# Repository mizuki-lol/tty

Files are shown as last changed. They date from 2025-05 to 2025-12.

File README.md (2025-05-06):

# Převodník ASCII na ITA-2

Tento projekt slouží k připojení zařízení pomocí sériového kabelu k dálnopisu.

## Konstrukce

K sestavení převodníku je potřeba:
  * Raspberry Pi Pico 1
  * Převodník RS-232 - TTL
  * 2x optočlen
  * 4x 300 Ohm rezistor
  * 1x LED dioda
  * Nepájivé pole
  * Dráty pro propojení součástek na nepájivém poli

Zapojte podle obrázku nebo dle schémata ve složce `schematics/`.
Dbejte na orientaci diody a optočlenů, správné zapojení je na obrázku.
Nezapomeňte připojit napěťovou smyčku dálnopisu k spodním napájecím kontaktům (označené + a -).
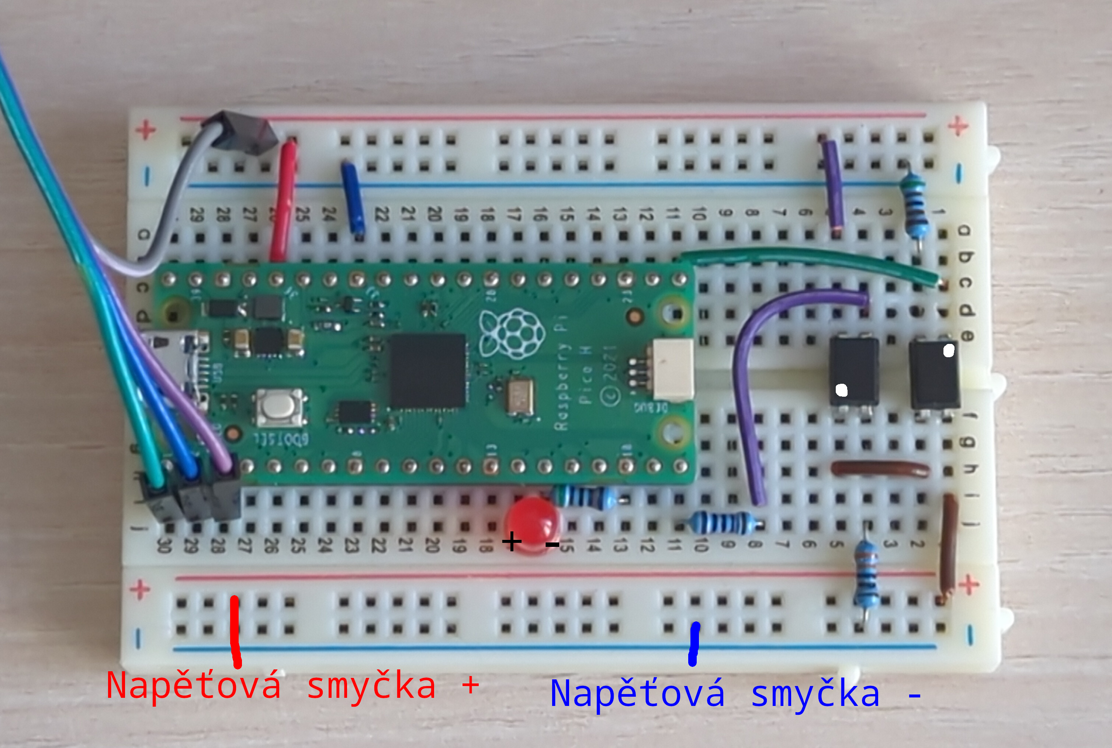
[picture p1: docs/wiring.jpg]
Zapojení na nepájivém poli

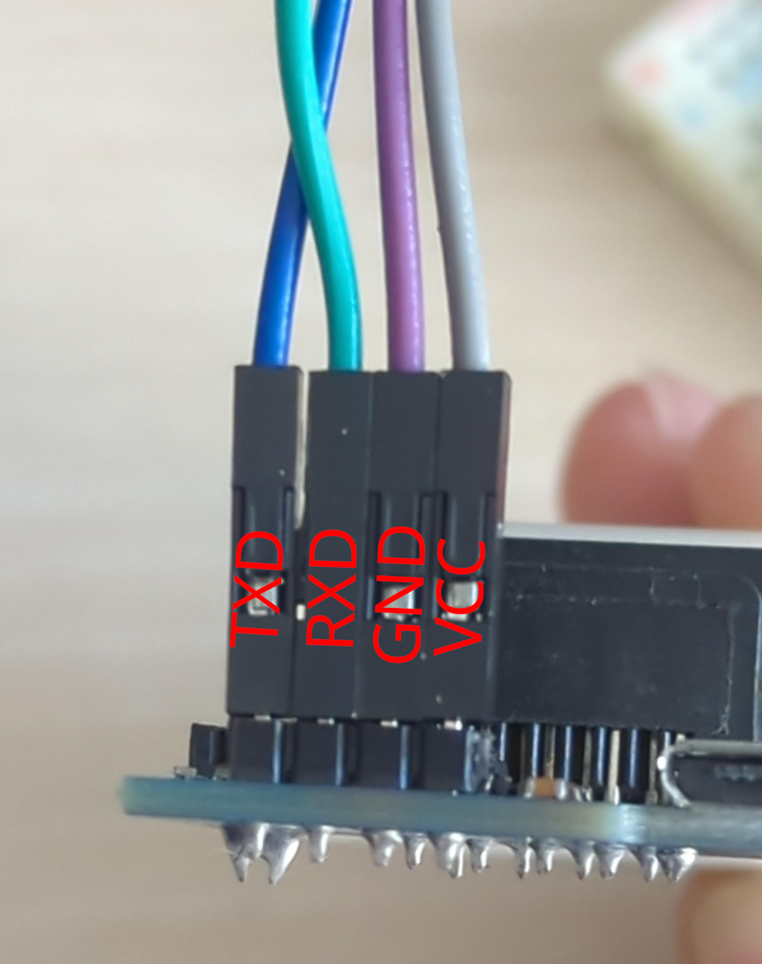
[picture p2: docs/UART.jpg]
Zapojení UARTu


## Kompilace & flashování

Závislosti:
  * [rustpup](https://rustup.rs/)    
  * Rust - verze 1.75 a vyšší
    * Nainstaluje spolu s rustupem
  * thumbv6m-none-eabi target pro rustc
    * lze získat tímto příkazem: `rustup target add thumbv6m-none-eabi`
  * elf2uf2-rs
    * lze získat tímto příkazem: `cargo install elf2uf2-rs`

```
# Kompilace projektu
cargo build --release

# Převedení na uf2
elf2uf2-rs target/thumbv6m-none-eabi/release/tty tty.uf2

# Nahrání na Rpi Pico.
# Připojte Rpi Pico k počítači pomocí Micro-usb kabelu zatímco držíte tlačítko BOOTSEL.
# (Tento krok není nutné dělat přes příkazový řádek a je možné ho udělat
# pomocí správce souborů.)
cp tty.uf2 <cesta k rpi> # Zaměňte <cesta k rpi> za složku kde se nachází Rpi Pico.
```

## Použití

Připojte k Rpi Picu zdroj napětí pomocí Micro-usb kabelu.
Připojte drát napěťové smyčky dálnopisu na příslušné piny.
Připojte svůj počítač sériovým kabelem k převodníku.
Zřiďte připojění k sériovému portu pomocí programu jako např. puTTY s nastavením:
  * Speed (baud) - 300
  * Data bits - 8
  * Stop bits - 1
  * Parity - None
  * Flow control - None  
Nezapomeňte také vypnout local-echo.

Nyní můžete psát text do puTTY, který se pošle dálnopisu.
Stejným způsobem se text poslaný dálnopisem zobrazí v puTTY.

Pokud se rozsvítí LED dioda to znamená že program převodníku spadnul,
v tomto případě odpojte a znovu připojte převodník od napájení.

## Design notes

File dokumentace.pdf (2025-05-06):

# Převodník ASCII na ITA-2

## Jakub Novák

C3c

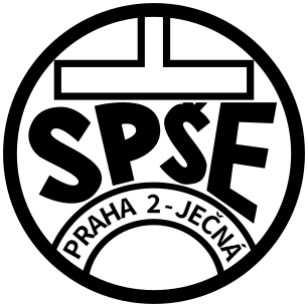
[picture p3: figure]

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
# Úvod

Tento projekt byl vytvořen za účelem propojit moderní počítač k dálnopisu nebo telexu. Problematika spočívá v rozlišných kódování znakových sad.
Počítače univerzálně podporují znakovou sadu ASCII, která byla vytvořena až poté, co se standardizovala Mezinárodní telegrafní abecedu č. 2 (ITA-2), kterou používají dálnopisy. ITA-2 je 5-bitové kódování latinské abecedy, čísel a menšího rozsahu speciálních znaků než ASCII. Největším rozdílem mezi ASCII a ITA-2 není jiné kódování jednotlivých znaků ale to, že ITA-2 může být ve dvou stavech. Buď může přenášet znaky ze sady písmen (LTRS) anebo figur (FIGS). Mezi těmito sadami se přepíná pomocí speciálních kontrolních znaků. Dvě sady znaků v ITA-2 jsou použity kvůli nízkému počtu bitů pro zakódování znaků. Pokud by dvou znakových sad nebylo využito, nemohla by v ITA-2 být zahrnutá celá latinská abeceda společně i s čísly vzhledem k tomu, že by bylo potřeba 36 různých bitových kombinací. Tolik kombinací není možno znázornit pouze v 5 bitech (maximum je 32), a proto tedy bylo využito více znakových sad.
Dálnopisy jsou mezi sebou propojeny napěťovou smyčku. Tato napěťová smyčka se používá pro asynchronní sériovou komunikaci mezi zařízeními. Standardně se posílají data rychlostí 50 baudů, a proto, aby se nepřehltil, převodník obsahuje vyrovnávací paměť pro ukládání znaků, které ještě neposlal.
Jako poslední funkce převodníku je překládání zakončení řádků. Některé operační systémy (zejména ty založené na UNIXu) používají pro odřádkování pouze znak Line Feed (LF). Dálnopisy však očekávají také před LF také Carriage Return (CR). Pro dálnopis LF znamená že se papír posune o řádek výš. Většinou však operátor chce také posunout psací hlavu na začátek řádku, k tomu slouží CR, proto je nutné posílat jak LF, tak CR.

# Ekonomická rozvaha

Vzhledem ke stáří dálnopisů se tento převodník nesetkává s velkou konkurencí. Jediný podobný komerční převodník (který bylo na internetu možné najít) není univerzální, nýbrž je určen pro Teletype Model 33 a stojí $49

[1]
. Tento projekt proto
vyčnívá svojí cenovou dostupností díky nízkému nákladu na potřebné komponenty. Avšak cenová dostupnost nezaručí popularitu mezi zákazníky. Převodníky jako je tento lze spíše najít jako open-source projekty, kvůli tomu že dálnopisy používají nejčastěji už jen zájemci, kteří jsou náchylnější k tomu si vytvořit vlastní převodník a publikovat ho na internet, než aby si kupovali komerční řešení.

# Vývoj

## Hardware

Nejdůležitější částí celého převodníku je samotný hardware, o kterém se v rámci vývoje rozhodovalo prvně.
Pro komunikaci se využilo připojení RS-232 přes sériový kabel, které bylo shledáno jako ideální díky jednoduchosti předášení libovolných ASCII znaků oproti rozhraním jako např. USB. Samotné převádění znaků z ASCII na ITA-2 se provádí v softwaru, který musí běžet na nějakém microcontrolleru.
Pro tento účel bylo vybráno Raspberry Pi Pico 1. Výběr microcontrolleru nepodstoupil hlubokému rozhodování vzhledem k nízkým požadavkům a to jen pouze: UART periferie a pár GPIO pinů.
Jako poslední důležitá hardwarová část převodníku je přerušování napěťové smyčky. Nejprve pro tento účel byly použity tranzistory, avšak po testu tohoto řešení se objevilo že jejich zapojení bylo příliš komplikované. Proto se využilo optočlenů.
Nejenom se zapojení celého obvodů výrazně zjednodušilo, ale také se napěťová smyčka a obvod, který pracuje s RPI Picem, opticky oddělí.

## Software

Vývoj softwaru se učinil v programovacím jazyce Rust. Tento jazyk byl hlavně vybrán kvůli své osobní preferenci. Při vývoji se projevilo že toto rozhodnutí bylo správné. Knihovny pro abstrakci práce s RPI Picem a funkce samotného jazyka výrazně zpříjemnily vývoj, který díky nim proběhl hladce.

# Testování

Vzhledem k nedostupnosti dálnopisu testování proběhlo pouze lokálně, pomocí přivedení stálého napětí na napěťovou smyčku.
Totiž, když se na počítači k sériovému portu (např. pomocí programu picocom[2]
), znaky, které napíšete na klávesnici, se nezobrazí na obrazovce, protože se pouze pošlou, ale nejsou přečteny zpět. (Toto tvrzení je za předpokladu že je v softwaru vypnutá funkce local-echo, která by měla být vypnutá pro správný chod převodníku.) Tyto poslané znaky jsou obdržené převodníkem, který je pošle na napěťovou smyčku. A vzhledem k tomu že čtení a zápis na napěťovou smyčku jsou od sebe kompletně odděleny, tak se rovnou z napěťové smyčky přečte a pošle počítači zpět. Tímto lze ověřit, že pokud se na obrazovce počítače objeví to co operátor zadal, tak musí jak čtení, tak zápis fungovat správně.

# Nasazení

Pro použití je potřeba samotného převodníku, dálnopisu a počítače. V dnešní době už počítače nedisponují podporou RS-232, takže bude také potřeba převodníku USB mezi RS-232. Ty, na rozdíl od tohoto, jsou naštěstí komerčně dostupné. Propojení dálnopisu není limitované pouze na počítače. Terminály jako např. VT100, používané jako přístupové body k mainframům, také posílaly ASCII přes RS-232, a proto je možné jich využít místo plnohodnotných počítačů.

# Licence

Celý zdrojový kód a zapojení hardwaru je licencováno pod copyleftovou open-source licencí Mozilla Public License.

# Zdrojový kód

Všechen kód je dostupný z těchto git repozitářů:
1. https://git.sr.ht/~xalfer/tty
2. https://github.com/mizuki-lol/tty

# Závěr

Tento projekt my dal možnost setkat se a objevit staré avšak nezapomenuté technologie. Během vývoje jsem měl možnost využít nejen svých znalostí programování, ale i elektrotechniky, a proto mi přišel tak zajímavý. Lituji toho, že jsem neměl možnost otestovat převodník s plně funkčním dálnopisem, avšak jsem spokojený i s konečným výsledkem, ačkoli není stoprocentně perfektní.

# Zdroje

[1] - https://deramp.com/tty_adapter.html
[2] - https://github.com/npat-efault/picocom

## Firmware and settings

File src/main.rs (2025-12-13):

#![no_std]
#![no_main]

use tty::Teletype;

use core::fmt::Write;
use core::panic::PanicInfo;
use embedded_hal::digital::OutputPin;
use rp_pico::{
    entry,
    hal::{
        self,
        fugit::{ExtU32, MicrosDurationU32, RateExtU32},
        timer::Alarm,
        uart::{DataBits, StopBits, UartConfig, UartPeripheral},
        Clock, Sio, Timer,
    },
    pac::{self},
};

#[entry]
fn main() -> ! {
    let mut pac = pac::Peripherals::take().unwrap();
    let mut watchdog = hal::Watchdog::new(pac.WATCHDOG);
    let clocks = hal::clocks::init_clocks_and_plls(
        rp_pico::XOSC_CRYSTAL_FREQ,
        pac.XOSC,
        pac.CLOCKS,
        pac.PLL_SYS,
        pac.PLL_USB,
        &mut pac.RESETS,
        &mut watchdog,
    )
    .ok()
    .unwrap();
    let sio = Sio::new(pac.SIO);
    let pins = hal::gpio::Pins::new(
        pac.IO_BANK0,
        pac.PADS_BANK0,
        sio.gpio_bank0,
        &mut pac.RESETS,
    );

    let uart_pins = (pins.gpio0.into_function(), pins.gpio1.into_function());
    let mut current_loop_write = pins.gpio16.into_push_pull_output();
    let current_loop_read = pins.gpio15.into_pull_down_input();
    let current_loop_read_rev = pins.gpio14.into_pull_down_input();
    let begin_call_write = pins.gpio17.into_push_pull_output();
    let mut led = pins.gpio25.into_push_pull_output();

    let mut uart = UartPeripheral::new(pac.UART0, uart_pins, &mut pac.RESETS)
        .enable(
            UartConfig::new(300.Hz(), DataBits::Eight, None, StopBits::One),
            clocks.peripheral_clock.freq(),
        )
        .unwrap();

    writeln!(uart, "tty start\r").unwrap();

    current_loop_write.set_high().unwrap();

    let mut timer = Timer::new(pac.TIMER, &mut pac.RESETS, &clocks);
    let mut read_alarm = timer.alarm_0().unwrap();
    let mut write_alarm = timer.alarm_1().unwrap();
    read_alarm.disable_interrupt();
    write_alarm.disable_interrupt();
    read_alarm.schedule(3.millis()).unwrap();
    write_alarm.schedule(3.millis()).unwrap();

    let mut tty = Teletype::new(
        current_loop_read,
        current_loop_read_rev,
        current_loop_write,
        begin_call_write,
    );

    let mut buf = [0; 32]; // this is enough to hold the entire pico uart read buffer

    // main loop
    loop {
        // Connect to peer
        'connection: loop {
            if tty.accept_conn(&mut timer) {
                break;
            }
            let nread = match uart.read_raw(&mut buf) {
                Ok(0) | Err(nb::Error::WouldBlock) => continue,
                Ok(n) => n,
                Err(e) => {
                    _ = write!(uart, "{e:?}");
                    continue;
                }
            };
            let digits = buf[0..nread]
                .iter()
                .filter(|c| c.is_ascii_digit())
                .map(|c| c - b'0');
            for d in digits {
                tty.dial(d, &mut timer);
                if tty.accept_conn(&mut timer) {
                    break 'connection;
                }
            }
        }

        writeln!(uart, "connected\r").unwrap();

        // Talk with peer
        while tty.is_connected() {
            if read_alarm.finished() {
                let (current_loop_state, read, sched) = tty.poll_read();
                _ = led.set_state(current_loop_state.into());
                if let Some(read) = read {
                    if read != 0 {
                        _ = uart.write_raw(&[read]);
                    }
                }
                read_alarm
                    .schedule(sched.unwrap_or(MicrosDurationU32::millis(3)))
                    .unwrap();
            }
            if write_alarm.finished() {
                let sched = tty.poll_write();
                write_alarm
                    .schedule(sched.unwrap_or(MicrosDurationU32::millis(3)))
                    .unwrap();
            }

            let nread = match uart.read_raw(&mut buf) {
                Ok(0) | Err(nb::Error::WouldBlock) => continue, // continue on empty reads
                Ok(n) => n,
                Err(e) => {
                    _ = writeln!(uart, "{e:?}\r");
                    continue;
                }
            };
            // Read end of transmission
            if buf[0..nread].iter().any(|&c| c == 4) {
                break;
            }
            let (str, len) = translate(buf, nread);
            str[0..len].iter().for_each(|&c| {
                tty.queue_write(c);
            });
        }

        writeln!(uart, "disconnected\r").unwrap();
    }
}

/// Translate lone \n sent by the computer to \r\n.
fn translate(string: [u8; 32], strlen: usize) -> ([u8; 64], usize) {
    let mut output = [0; 64];
    let mut offset = 0;
    for (idx, c) in string[..strlen].iter().enumerate() {
        match c {
            b'\n' | b'\r' => {
                if idx >= 1
                    && (string[idx - 1] == b'\r' && *c == b'\n'
                        || string[idx - 1] == b'\n' && *c == b'\r')
                {
                    continue;
                }
                output[idx + offset] = b'\r';
                offset += 1;
                output[idx + offset] = b'\n';
            }
            c => output[idx + offset] = *c,
        }
    }
    (output, strlen + offset)
}

#[panic_handler]
fn panic(_info: &PanicInfo) -> ! {
    loop {}
}

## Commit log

2025-04-20 remove some error handling
    The program crashing is less desirable than no handling the errors at all
    in some places, most notably when writing to gpio pins.
    [main.rs]
2025-04-27 fix reading and writing on the current loop
    [main.rs]
2025-04-27 fix bug with switching shift state too quickly
2025-05-02 change current loop control pins
    this is just so that the wiring can be a bit clearer
2025-05-04 add schematics
    [schematics.kicad_pcb, schematics.kicad_sch]
2025-05-04 move schematics up a directory level
    [schematics.kicad_pcb, schematics.kicad_sch]
2025-05-04 finish schematics
    [schematics.kicad_sch]
2025-05-04 remove schematics backups
2025-05-04 update wiring image
